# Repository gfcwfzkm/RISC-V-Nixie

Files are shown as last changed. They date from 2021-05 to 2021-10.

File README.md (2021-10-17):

# RISC-V-Nixie
Nixie Clock using the GD32VF103 RISC-V microcontroller by GigaDevices and the swiss precise RTC RV-3032-C7 by Micro Crystal AG.

For tubes, IN-8 tubes will be used as they can be mounted into sockets. Since the original, soviet sockets are quite bulky, individual pin sockets will be mounted instead.

## Status
The current status of the project, which steps are done or still need to be do. Currently only revision A is in testing, a revision that has some slight imperfections that will be tackled in the next revision. Since parts have been already delivered, revision A will be used to extensively test the PCB, in particular the dimming of the tubes and the high-voltage step-up circuitery.
Task | Comments
------------ | -------------
Initial Schematic | :heavy_check_mark:
Initial Layout & BOM | :heavy_check_mark:
Assembling PCB | :heavy_check_mark:
Power-ON Test, Voltage levels | :heavy_check_mark:
Initialising / Testing the MCU | :heavy_check_mark:
Writing basic I/O functions | In Progress... :grey_question:
Writing the clock programm | -

## Images
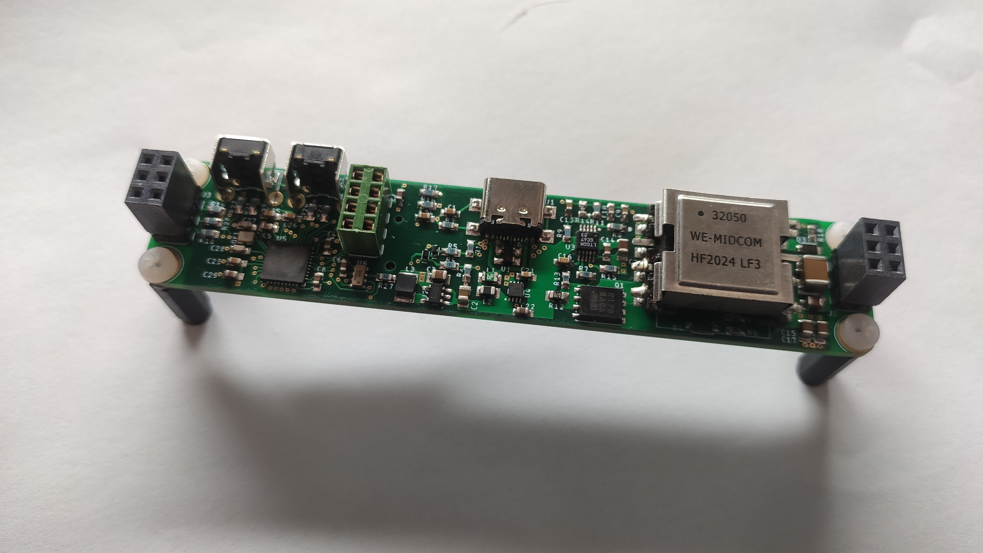
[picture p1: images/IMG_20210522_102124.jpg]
Lower assembled PCB

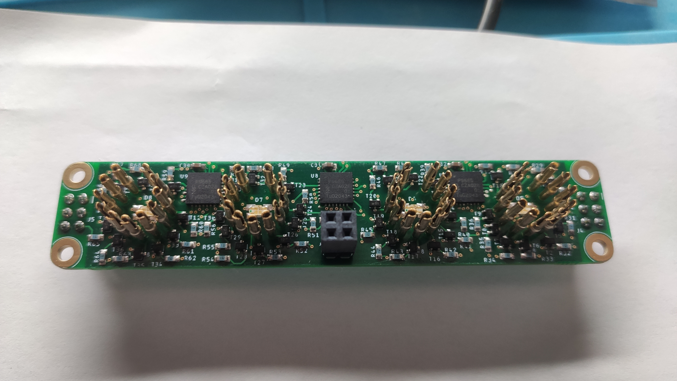
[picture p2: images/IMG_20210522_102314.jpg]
Upper assembled PCB

PCBs + Tubes assembled
Conformal coating TOP
Conformal coating BOTTOM
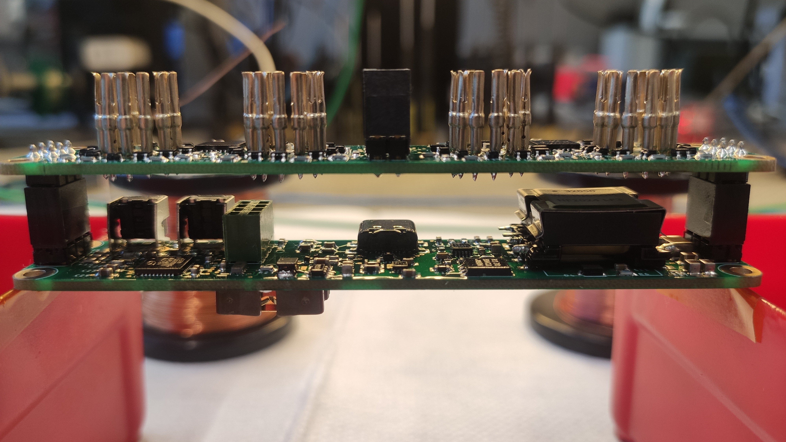
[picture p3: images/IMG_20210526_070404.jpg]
Spacing between high-voltage pins of the upper PCB and the lower PCB's buttons / transformer

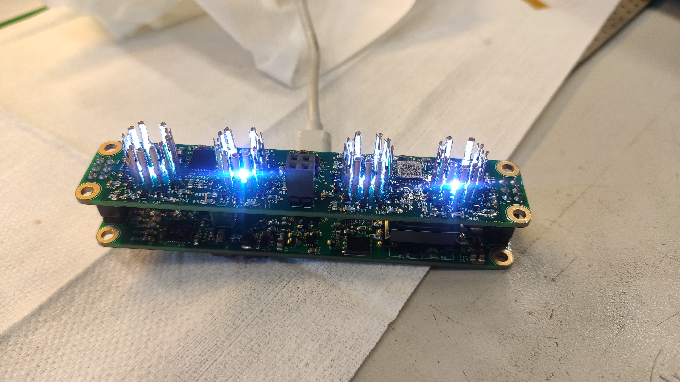
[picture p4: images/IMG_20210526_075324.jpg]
Initial Power test, no magic smoke & all voltages within specs!


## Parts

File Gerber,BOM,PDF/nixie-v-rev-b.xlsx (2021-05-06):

Qty | Value | Device | Package | Parts | Digikey | TME | Ebay | Price single | Price total
1 |  | CONN_02 | 1X02 | J7 | SAM11071-ND |  |  | CHF 1.58 | CHF 1.58
4 |  | WL-SFRW_1206_REC_156120M173000_NOR | WL-SFRW_1206_REC | D5, D6, D7, D8 | 732-13408-1-ND |  |  | CHF 0.87 | CHF 3.48
1 | 1.05M | R-EU_R0603 | R0603 | R10 | RMCF0603FT1M05CT-ND |  |  | CHF 0.09 | CHF 0.09
40 | 1.3k | R-EU_R0603 | R0603 | R29, R30, R31, R32, R33, R34, R35, R36, R37, R38, R39, R40, R41, R42, R43, R44, R45, R46, R47, R48, R49, R50, R51, R52, R53, R54, R55, R56, R57, R58, R59, R60, R61, R62, R63, R64, R65, R66, R67, R68 | 2019-RK73H1JTTD1301FCT-ND |  |  | CHF 0.02 | CHF 0.80
6 | 10 | R-EU_R0603 | R0603 | R7, R13, R70, R75, R78, R81 | 2019-RK73H1JTTD10R0FCT-ND |  |  | CHF 0.09 | CHF 0.54
1 | 10.5k | R-EU_R0603 | R0603 | R11 | 2019-RK73H1JTTD1052FCT-ND |  |  | CHF 0.09 | CHF 0.09
2 | 100 | R-EU_R0603 | R0603 | R4, R5 | 2019-RK73H1JTTD1000FCT-ND |  |  | CHF 0.09 | CHF 0.18
1 | 100k | R-EU_R0603 | R0603 | R24 | 2019-RK73H1JTTD1003FCT-ND |  |  | CHF 0.09 | CHF 0.09
4 | 100nF | C-EUC0603 | C0603 | C1, C24, C25, C26 | 399-C0603C104M5RACAUTOCT-ND |  |  | CHF 0.09 | CHF 0.36
1 | 100pF | C-EUC0603 | C0603 | C10 | 1276-2162-1-ND |  |  | CHF 0.09 | CHF 0.09
7 | 10k | R-EU_R0603 | R0603 | R3, R6, R8, R15, R16, R20, R22 | 2019-RK73H1JTTD1002FCT-ND |  |  | CHF 0.09 | CHF 0.63
1 | 10nF | C-EUC0603 | C0603 | C23 | 445-5662-1-ND |  |  | CHF 0.09 | CHF 0.09
1 | 10uF | C-EUC0805 | C0805 | C3 | 445-173674-1-ND |  |  | CHF 0.44 | CHF 0.44
4 | 115 | R-EU_R0603 | R0603 | R72, R73, R76, R79 | 541-115HCT-ND |  |  | CHF 0.09 | CHF 0.36
1 | 180k | R-EU_R0603 | R0603 | R14 | 2019-RK73H1JTTD1803FCT-ND |  |  | CHF 0.09 | CHF 0.09
4 | 191 | R-EU_R0603 | R0603 | R71, R74, R77, R80 | 2019-RK73H1JTTD1910FCT-ND |  |  | CHF 0.09 | CHF 0.36
11 | 1uF | C-EUC0603 | C0603 | C4, C5, C6, C7, C8, C14, C22, C29, C30, C31, C32 | 445-173628-1-ND |  |  | CHF 0.17 | CHF 1.84
1 | 2.2nF | C-EUC0603 | C0603 | C11 | 1276-6530-1-ND |  |  | CHF 0.09 | CHF 0.09
1 | 20m | R-EU_R0805 | R0805 | R12 | CRF0805-FZ-R020ELFCT-ND |  |  | CHF 0.43 | CHF 0.43
2 | 22 | R-EU_R0603 | R0603 | R25, R26 | 2019-RK73H1JTTD22R0FCT-ND |  |  | CHF 0.09 | CHF 0.18
2 | 22nF | C-EUC0603 | C0603 | C9, C13 | 1276-6534-1-ND |  |  | CHF 0.09 | CHF 0.18
4 | 22uF | C-EUC0805 | C0805 | C15, C17, C18, C20 | 490-12342-1-ND |  |  | CHF 0.52 | CHF 2.08
4 | 3.3k | R-EU_R0603 | R0603 | R18, R19, R27, R28 | 2019-RK73H1JTTD3301FCT-ND |  |  | CHF 0.09 | CHF 0.36
1 | 3.3nF | C-EUC0603 | C0603 | C16 | 478-06035C332K4T2ACT-ND |  |  | CHF 0.09 | CHF 0.09
1 | 30.9k | R-EU_R0603 | R0603 | R9 | 2019-RK73H1JTTD3092FCT-ND |  |  | CHF 0.09 | CHF 0.09
3 | 330 | R-EU_R0603 | R0603 | R17, R21, R23 | 2019-RK73H1JTTD3300FCT-ND |  |  | CHF 0.09 | CHF 0.27
2 | 3V | VESD05A1-02V-G3-08 | SOD-523 | D1, D2 | VESD03C1-02VHG3-08GICT-ND |  |  | CHF 0.35 | CHF 0.70
1 | 3v 1220 Battery | BATTERY1056_KEYSTONE | CH291-1220LF | BT1 | 36-1056-ND |  |  | CHF 1.35 | CHF 1.35
1 | 4.7uF | C-EUC0805 | C0805 | C2 | 587-6301-1-ND |  |  | CHF 0.33 | CHF 0.33
1 | 4.7uH | L1210 | R1210 | L3 | 490-16010-1-ND |  |  | CHF 0.32 | CHF 0.32
1 | 470nF | C-EUC1812 | C1812 | C12 | 445-7993-1-ND |  |  | CHF 1.66 | CHF 1.66
2 | 5.1k | R-EU_R0603 | R0603 | R1, R2 | 2019-RK73H1JTTD5101FCT-ND |  |  | CHF 0.09 | CHF 0.18
1 | 5.4k | R-EU_R0603 | R0603 | R69 | 2019-RN73H1JTTD5421B50CT-ND |  |  | CHF 0.45 | CHF 0.45
1 | 6.8pF | C-EUC0603 | C0603 | C19 | 399-15762-1-ND |  |  | CHF 0.29 | CHF 0.29
1 | 680pF | C-EUC0603 | C0603 | C21 | 399-20505-1-ND |  |  | CHF 0.35 | CHF 0.35
1 | 750032050 | 750032050 | 750032050 | L4 | 732-2128-1-ND |  |  | CHF 4.34 | CHF 4.34
1 | 8MHz | RESONATOR-8MHZSMD_3.2X1.3 | RESONATOR-SMD-3.2X1.3 | Y1 | 490-17958-1-ND |  |  | CHF 0.23 | CHF 0.23
2 | Switch Omron | 31-XX | B3F-31XX | S1, S2 | SW1050-ND |  |  | CHF 0.41 | CHF 0.82
1 | ESH1JMRSG | ESH1JMRSG | MICROSMA | D3 | ESH1JMRSGCT-ND |  |  | CHF 0.41 | CHF 0.41
1 | ESP-01 | CONN_04X2 | 2X4 | J6 | A106657-ND |  |  | CHF 1.21 | CHF 1.21
2 | FromLowerPCB | CONN_03X2FEMALE | 2X3 | J4, J5 | 609-5718-ND |  |  | CHF 0.40 | CHF 0.80
1 | GD32VF103T | GD32VF103T | QFN-36 | U5 |  | GD32VF103TBU6 |  | CHF 2.30 | CHF 2.30
1 | Ih 750mA | PTC_FUSE0805 | R0805 | L1 | 507-1814-1-ND |  |  | CHF 0.16 | CHF 0.16
1 | LT3757A_MSOP | LT3757A_MSOP | MSOP10_POWER | U3 | LT3757AEMSE#PBF-ND |  |  | CHF 4.96 | CHF 4.96
1 | MBR0520LT1G | MBR0520LT1G | SOD-123 | D4 | MBR0580S1-7DICT-ND |  |  | CHF 0.26 | CHF 0.26
1 | MCP1603 | MCP1603 | TSOT23-5 | U2 | MCP1603T-330I/OSCT-ND |  |  | CHF 0.93 | CHF 0.93
4 | MOUNT-PAD-ROUND2.8 |  |  |  | 732-13005-ND |  |  | CHF 0.95 | CHF 3.80
4 | MOUNT-PAD-ROUND2.8 |  |  |  | 732-12861-ND |  |  | CHF 0.55 | CHF 2.20
8 | MOUNT-PAD-ROUND2.8 |  |  |  | 145-50M025045P006-ND |  |  | CHF 0.13 | CHF 1.04
8 | MOUNT-PAD-ROUND2.8 | MOUNT-PAD-ROUND2.8 |  |  | RPC2983-ND |  |  | CHF 0.14 | CHF 1.12
41 | MSD42WT1G | MSD42WT1G | SC70-3-R | T1, T2, T3, T4, T5, T6, T7, T8, T9, T10, T11, T12, T13, T14, T15, T16, T17, T18, T19, T20, T21, T22, T23, T24, T25, T26, T27, T28, T29, T30, T31, T32, T33, T34, T35, T36, T37, T38, T39, T40, T41 | MSD42WT1GOSCT-ND |  |  | CHF 0.15 | CHF 6.12
3 | PCA9685BS | PCA9685BS | HVQFN28 | U7, U8, U9 | 568-5305-1-ND |  |  | CHF 2.28 | CHF 6.84
1 | PRTR5V0U2X | PRTR5V0U2X | SOT143B | U1 | 1727-3884-1-ND |  |  | CHF 0.43 | CHF 0.43
1 | RV-3032-C7 | RV-3032-C7 | RV-3028-C7 | U6 |  |  |  |  | CHF 0.00
1 | Reset | MOMENTARY-SWITCH-SPST-SMD-6.0X3.5MM | TACTILE_SWITCH_SMD_6.0X3.5MM | S3 | CKN10388CT-ND |  |  | CHF 0.50 | CHF 0.50
1 | SIR170DP | SIRA36DP | SO-08_POWERPAK | Q1 | SIR170DP-T1-RE3CT-ND |  |  | CHF 1.82 | CHF 1.82
4 | IN-8 | IN-8SMALL | IN-8 | N1, N2, N3, N4 |  |  | Random Ebay Seller | CHF 10.00 | CHF 40.00
40 | TubeSockets | TubeSockets | Socket | N1, N2, N3, N4 |  |  | RandomEbaySeller | CHF 0.10 | CHF 4.00
1 | TPS22965 | TPS22965 | WSON-8 | U4 | 296-42376-1-ND |  |  | CHF 0.93 | CHF 0.93
2 | ToUpperPCB | CONN_03X2FEMALE | 2X3 | J2, J3 | SAM15144-ND |  |  | CHF 1.97 | CHF 3.94
1 | USB41XX-GF-AMIXED | USB41XX-GF-AMIXED | USB4105-GF-A | J1 | 490-17958-1-ND |  |  | CHF 1.43 | CHF 1.43
1 | f-bead | L-COIL | R0805 | L2 | 445-172904-1-ND |  |  | CHF 0.11 | CHF 0.11
 |  |  |  |  |  |  |  | PRICE TOTAL | CHF 111.20

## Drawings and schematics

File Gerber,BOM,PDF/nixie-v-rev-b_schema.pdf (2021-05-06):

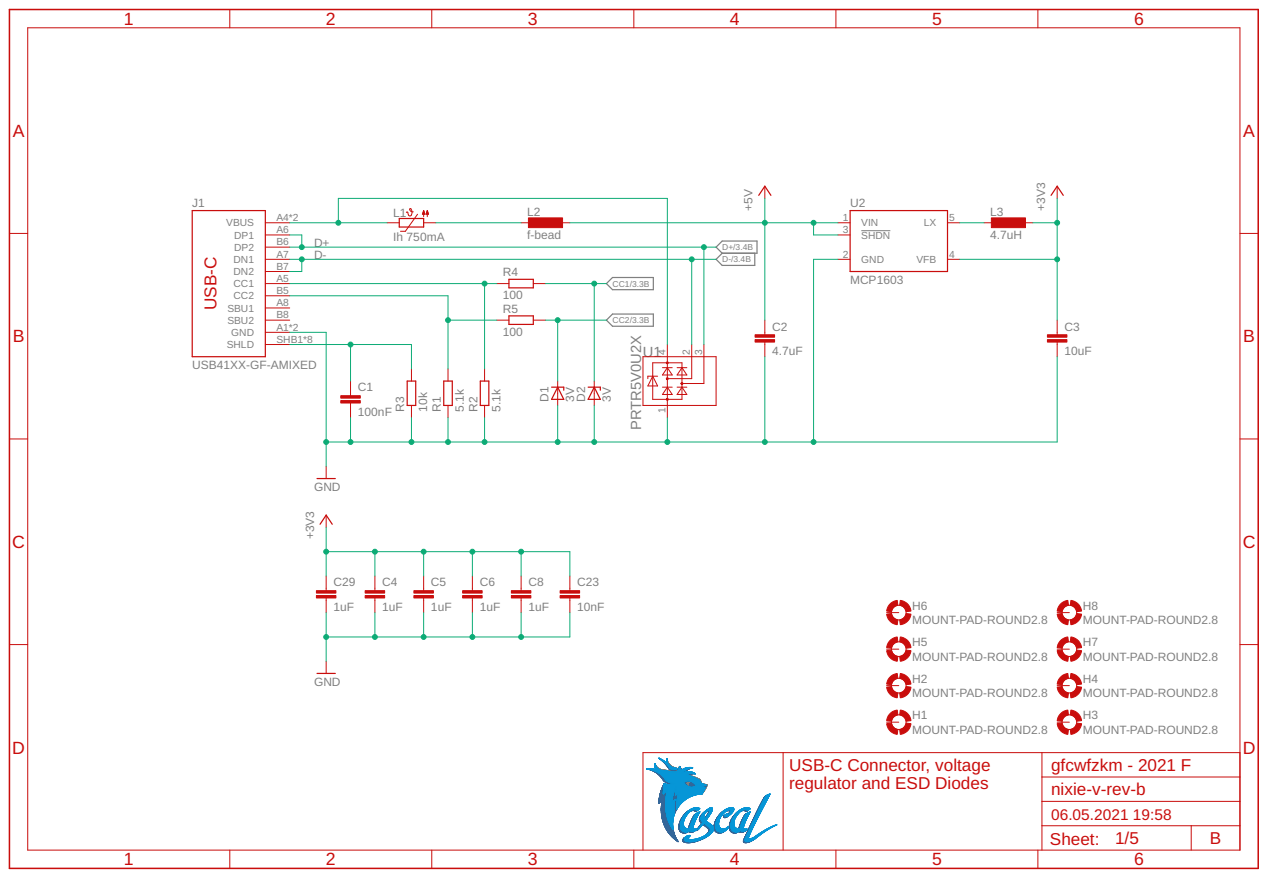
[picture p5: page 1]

regulator and ESD Diodes

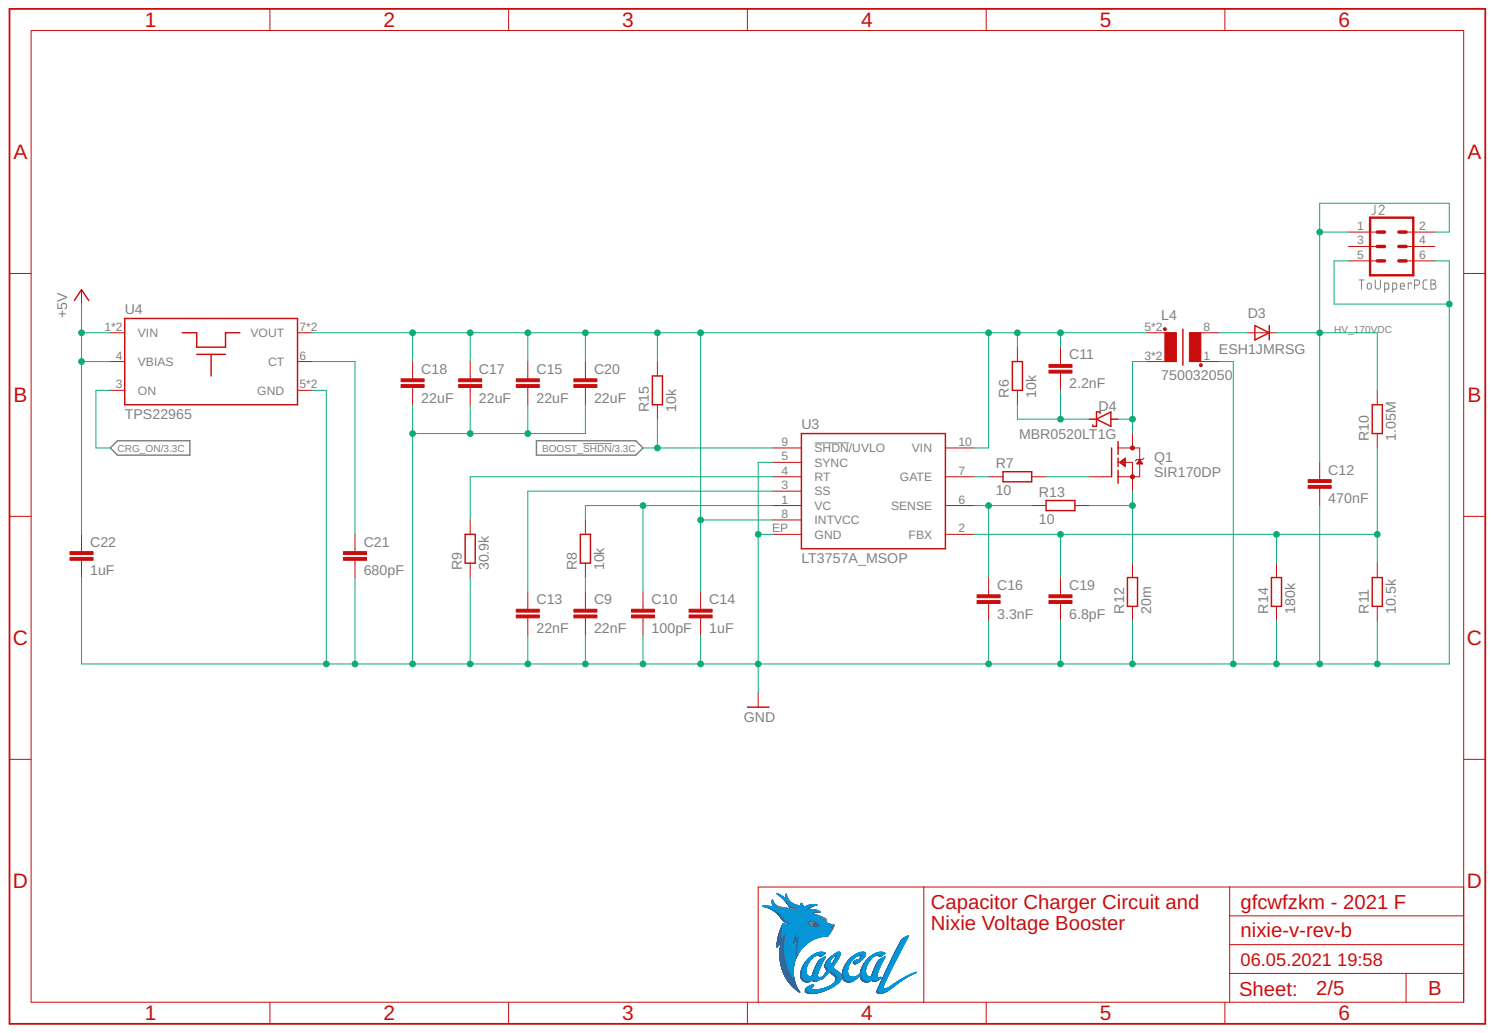
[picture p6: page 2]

Capacitor Charger Circuit and
Nixie Voltage Booster

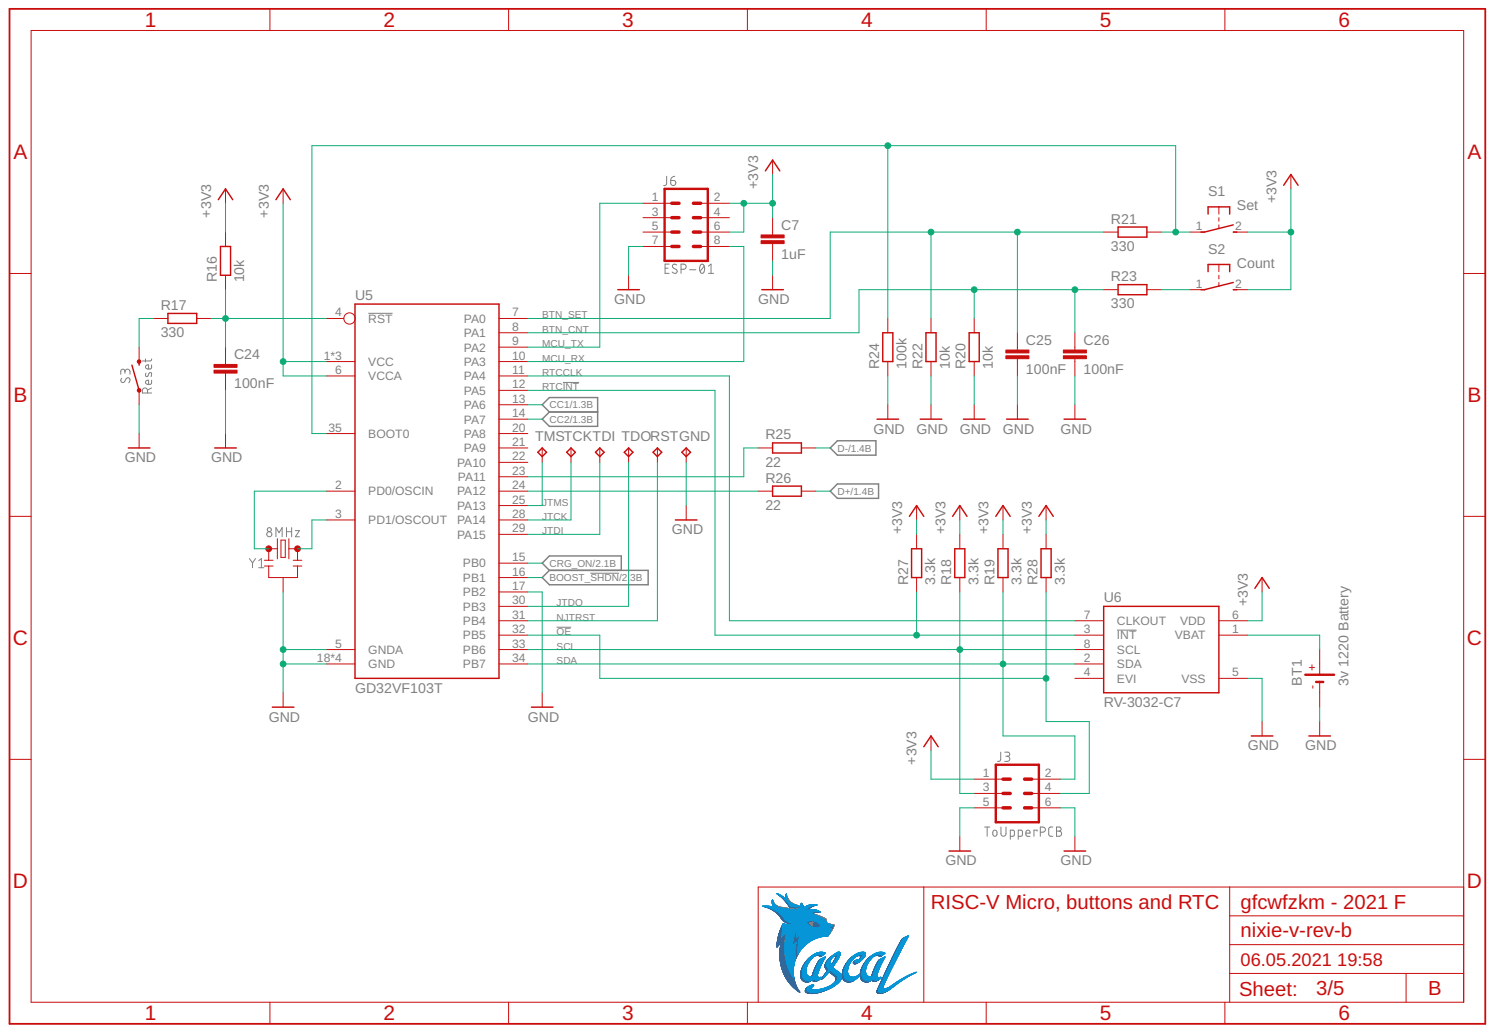
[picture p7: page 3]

8 PA0 BTN_CNT BTN_SET
9 PA1 MCU_TX MCU_RX

24 PA11
25 PA12 | JTCK

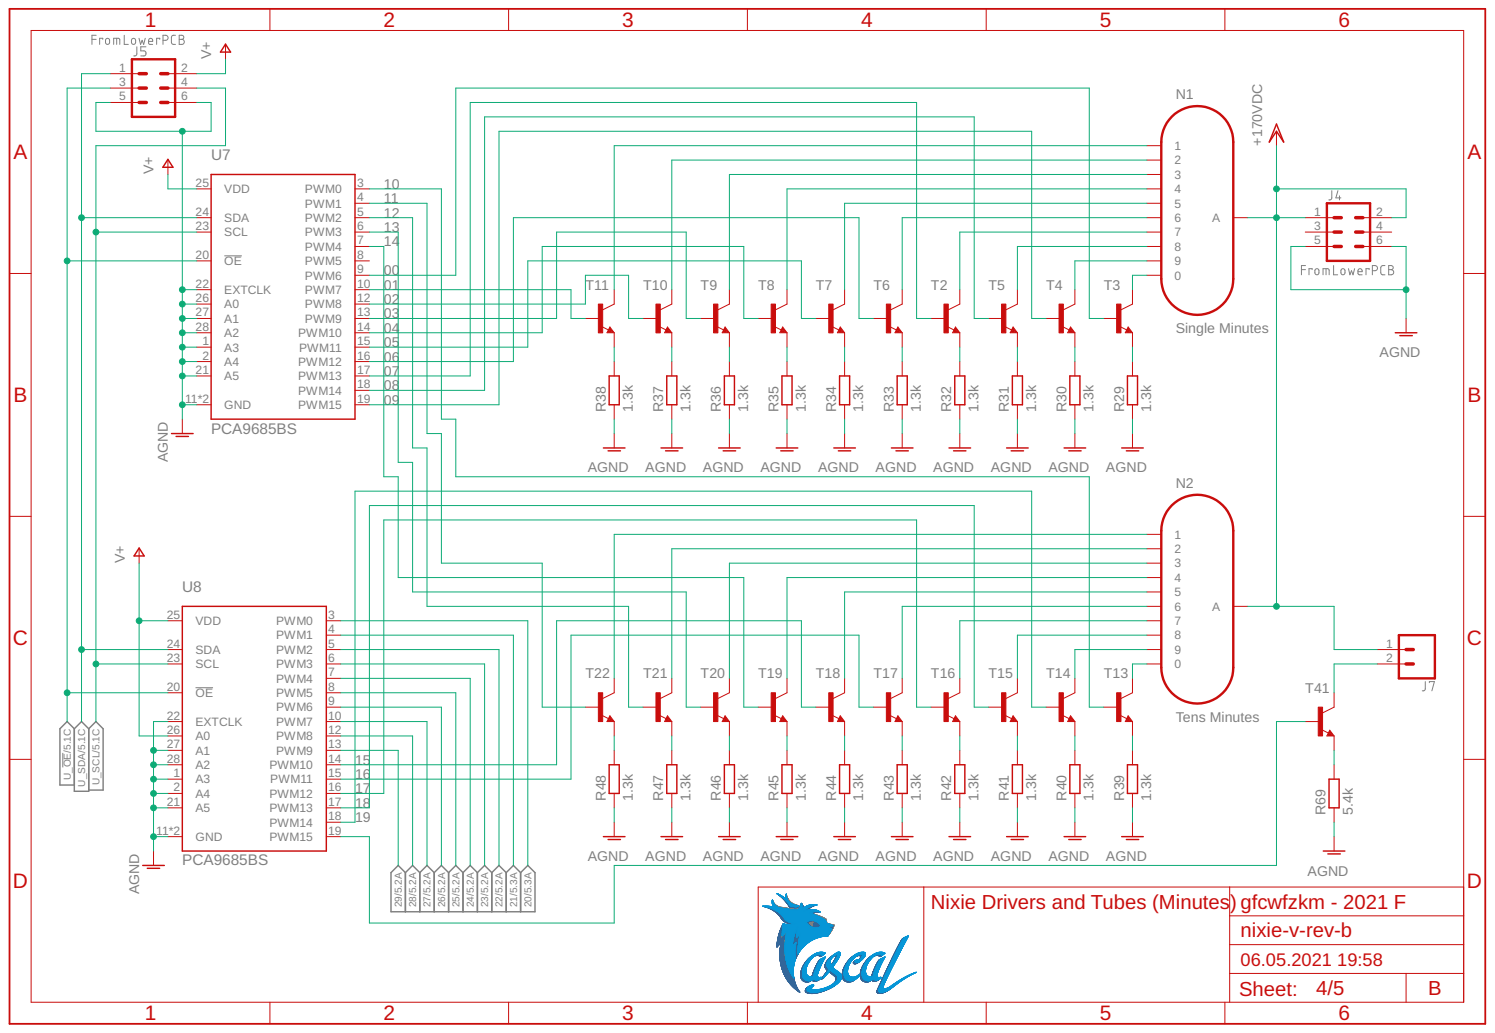
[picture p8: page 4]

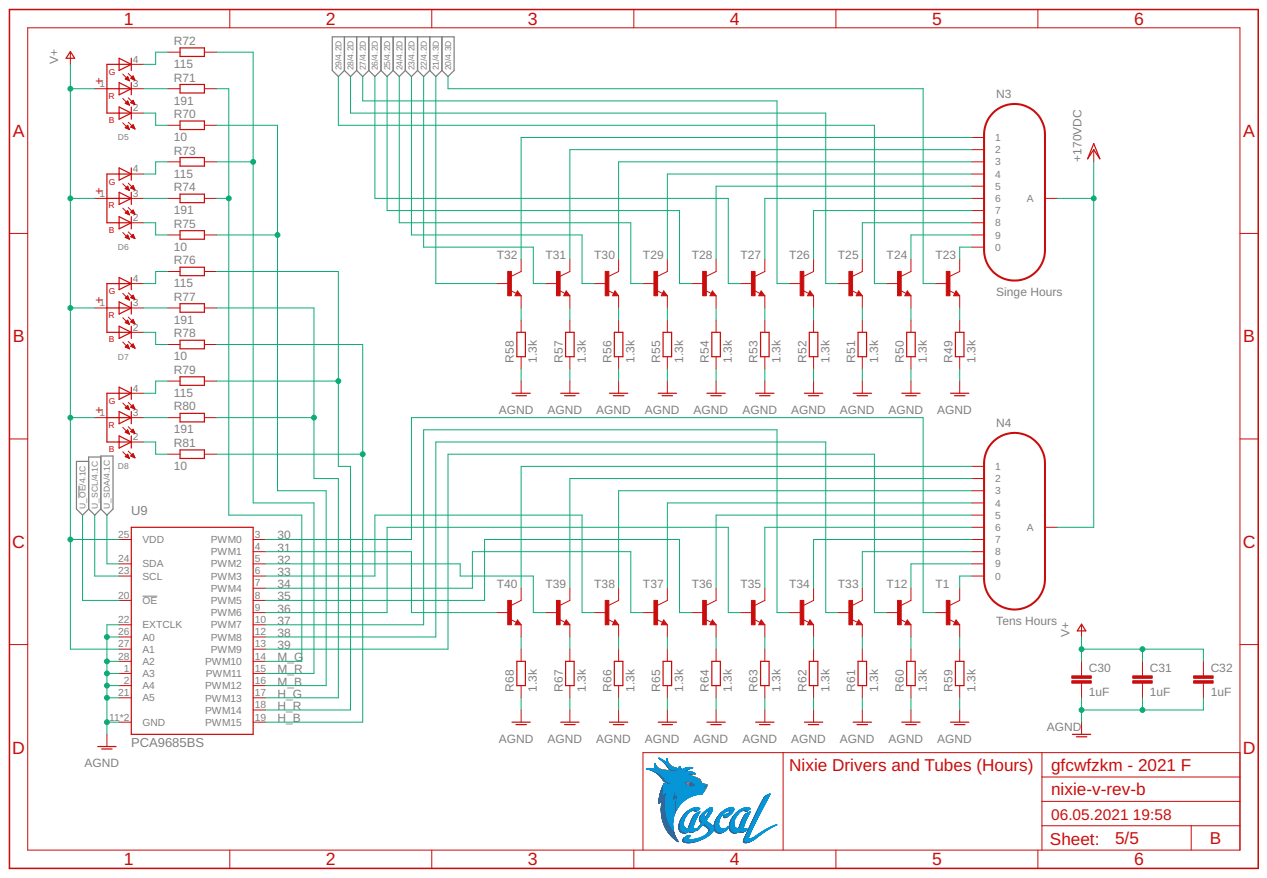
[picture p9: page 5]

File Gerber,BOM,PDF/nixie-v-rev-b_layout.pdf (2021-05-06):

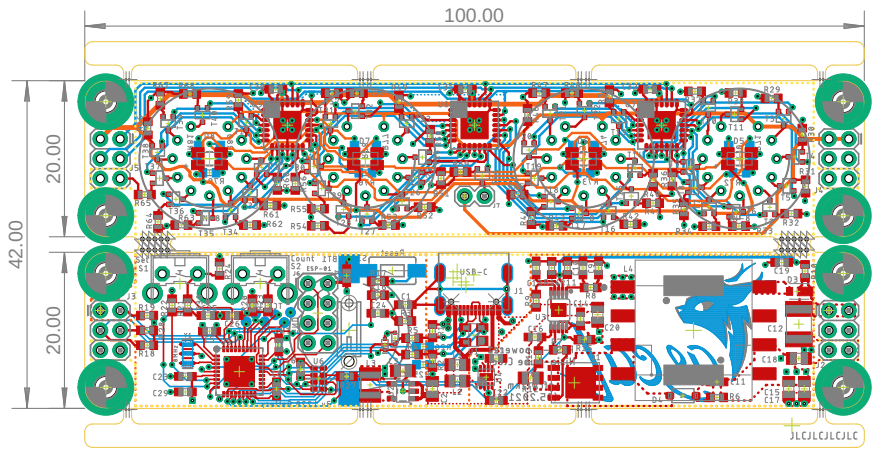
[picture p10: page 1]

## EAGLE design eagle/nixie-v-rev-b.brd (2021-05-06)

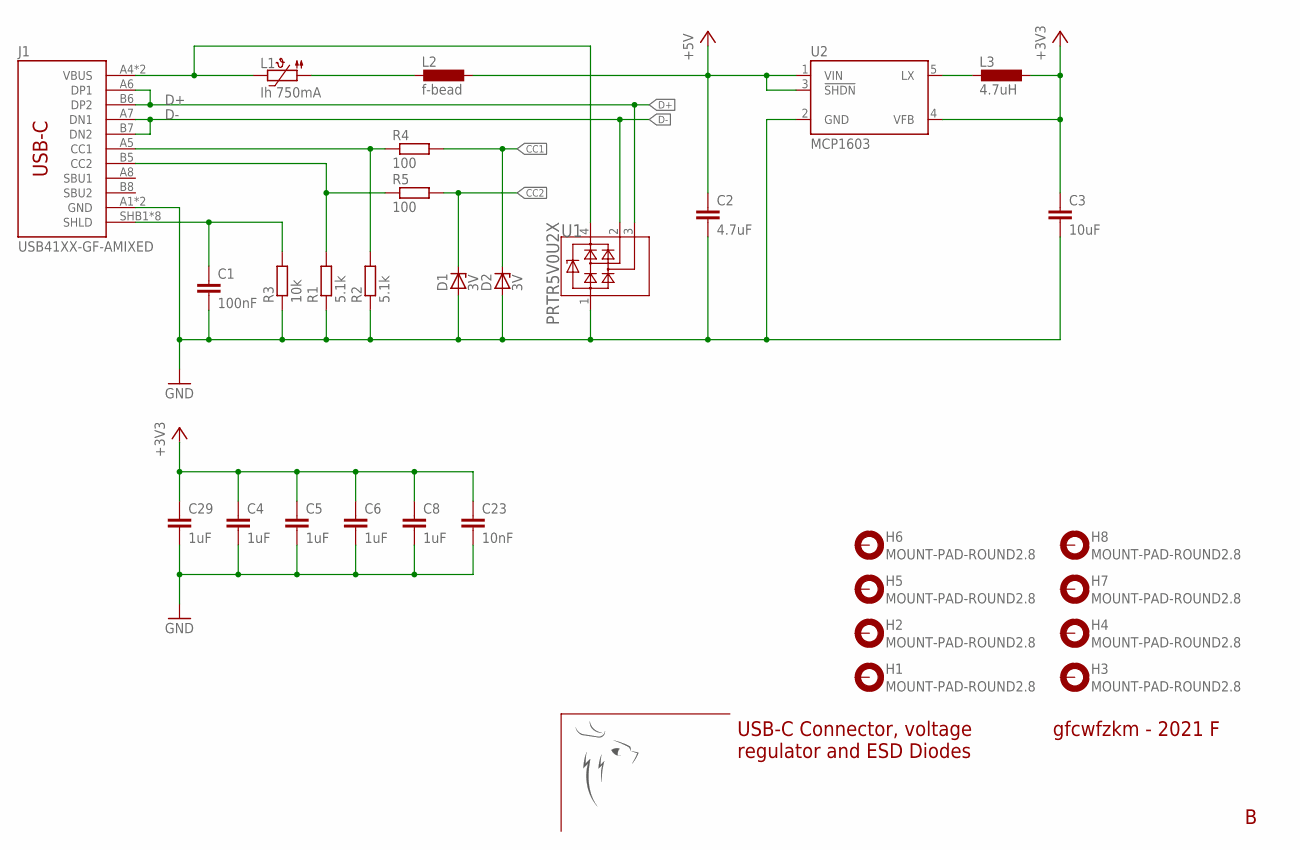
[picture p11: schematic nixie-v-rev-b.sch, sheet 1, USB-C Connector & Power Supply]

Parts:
C1: 100nF; C0603
C2: 4.7uF; C0805
C3: 10uF; C0805
C4, C5, C6, C8, C29: 1uF; C0603
C23: 10nF; C0603
D1, D2: 3V; SOD-523
H1, H2, H3, H4, H5, H6, H7, H8: MOUNT-PAD-ROUND2.8; 2,8-PAD
J1: USB41XX-GF-AMIXED; USB4105-GF-A
L1: Ih 750mA; R0805
L2: f-bead; R0805
L3: 4.7uH; R1210
R1, R2: 5.1k; R0603
R3: 10k; R0603
R4, R5: 100; R0603
U1: PRTR5V0U2X; SOT143B
U2: MCP1603; TSOT23-5
U$1: LOGO_PASCAL_GESELL30MM; LOGO_30MM

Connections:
+3V3: C3.1, C4.1, C5.1, C6.1, C8.1, C23.1, C29.1, L3.1, U2.4 (VFB); also elsewhere on the board
+5V: C2.1, L2.1, U2.1 (VIN), U2.3 (!SHDN); also elsewhere on the board
CC1: D2.C, R4.2; also elsewhere on the board
CC2: D1.C, R5.2; also elsewhere on the board
D+: J1.A6 (DP1), J1.B6 (DP2), U1.3; also elsewhere on the board
D-: J1.A7 (DN1), J1.B7 (DN2), U1.2; also elsewhere on the board
GND: C1.2, C2.2, C3.2, C4.2, C5.2, C6.2, C8.2, C23.2, C29.2, D1.A, D2.A, J1.A1 (GND), J1.B1 (GND), R1.1, R2.1, R3.1, U1.1, U2.2 (GND); also elsewhere on the board
LX: L3.2, U2.5 (LX)
unnamed: C1.1, J1.SHB1 (SHLD), J1.SHB2 (SHLD), J1.SHB3 (SHLD), J1.SHB4 (SHLD), J1.SHT1 (SHLD), J1.SHT2 (SHLD), J1.SHT3 (SHLD), J1.SHT4 (SHLD), R3.2
unnamed: J1.B5 (CC2), R1.2, R5.1
unnamed: J1.A5 (CC1), R2.2, R4.1
unnamed: L1.1, L2.2
VBUS: J1.A4 (VBUS), J1.B4 (VBUS), L1.2, U1.4

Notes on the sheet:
gfcwfzkm - 2021 F
USB-C Connector, voltage regulator and ESD Diodes

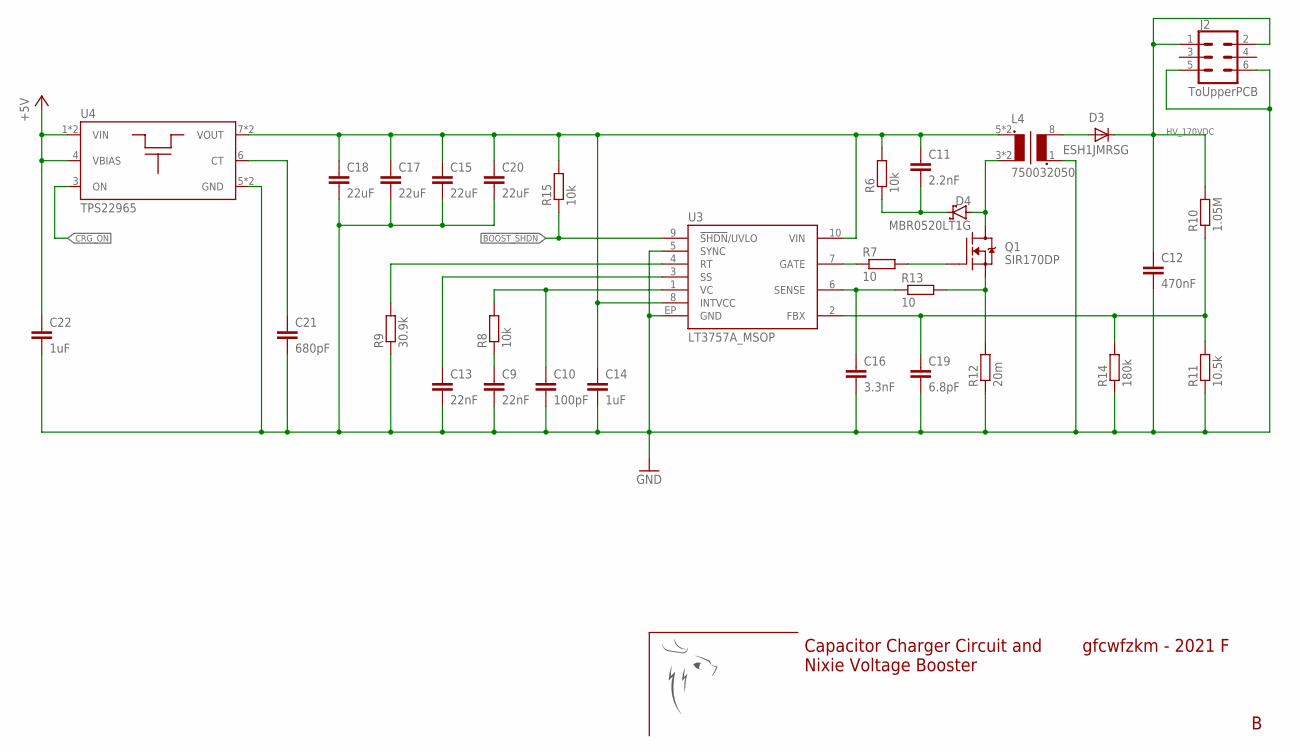
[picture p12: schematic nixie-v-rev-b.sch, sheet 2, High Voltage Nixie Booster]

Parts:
C9, C13: 22nF; C0603
C10: 100pF; C0603
C11: 2.2nF; C0603
C12: 470nF; C1812
C14, C22: 1uF; C0603
C15, C17, C18, C20: 22uF; C0805
C16: 3.3nF; C0603
C19: 6.8pF; C0603
C21: 680pF; C0603
D3: ESH1JMRSG; MICROSMA
D4: MBR0520LT1G; SOD-123
J2: ToUpperPCB; 2X3
L4: 750032050
Q1: SIR170DP; SO-08_POWERPAK
R6, R8, R15: 10k; R0603
R7, R13: 10; R0603
R9: 30.9k; R0603
R10: 1.05M; R0603
R11: 10.5k; R0603
R12: 20m; R0805
R14: 180k; R0603
U3: LT3757A_MSOP; MSOP10_POWER
U4: TPS22965; WSON-8
U$2: LOGO_PASCAL_GESELLEMPTY; EMPTY

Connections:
+5V: C22.1, U4.1 (VIN), U4.2 (VIN), U4.4 (VBIAS); also elsewhere on the board
BOOST_!SHDN: R15.1, U3.9 (!SHDN!/UVLO); also elsewhere on the board
CRG_ON: U4.3 (ON); also elsewhere on the board
FBX: C19.1, R10.1, R11.2, R14.2, U3.2 (FBX)
GATE: R7.1, U3.7 (GATE)
GND: C9.2, C10.2, C12.2, C13.2, C14.2, C15.2, C16.2, C17.2, C18.2, C19.2, C20.2, C21.2, C22.2, J2.5, J2.6, L4.1 (S1), R9.1, R11.1, R12.1, R14.1, U3.5 (SYNC), U3.EP (GND), U4.5 (GND), U4.TP (GND); also elsewhere on the board
HV_170VDC: C12.1, D3.C, J2.1, J2.2, R10.2
unnamed: C11.2, D4.C, R6.1
unnamed: Q1.4 (G), R7.2
unnamed: D3.A, L4.8 (S2)
unnamed: C9.1, R8.1
unnamed: Q1.1 (S), Q1.2 (S), Q1.3 (S), R12.2, R13.2
unnamed: D4.A, L4.3 (P2), L4.4 (P2), Q1.5 (D), Q1.6 (D), Q1.7 (D), Q1.8 (D), Q1.THERMAL (D)
unnamed: C21.1, U4.6 (CT)
RT: R9.2, U3.4 (RT)
SENSE: C16.1, R13.1, U3.6 (SENSE)
SS: C13.1, U3.3 (SS)
SUP_BOOST: C11.1, C14.1, C15.1, C17.1, C18.1, C20.1, L4.5 (P1), L4.6 (P1), R6.2, R15.2, U3.8 (INTVCC), U3.10 (VIN), U4.7 (VOUT), U4.8 (VOUT)
VC: C10.1, R8.2, U3.1 (VC)

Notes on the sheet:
Capacitor Charger Circuit and Nixie Voltage Booster
gfcwfzkm - 2021 F

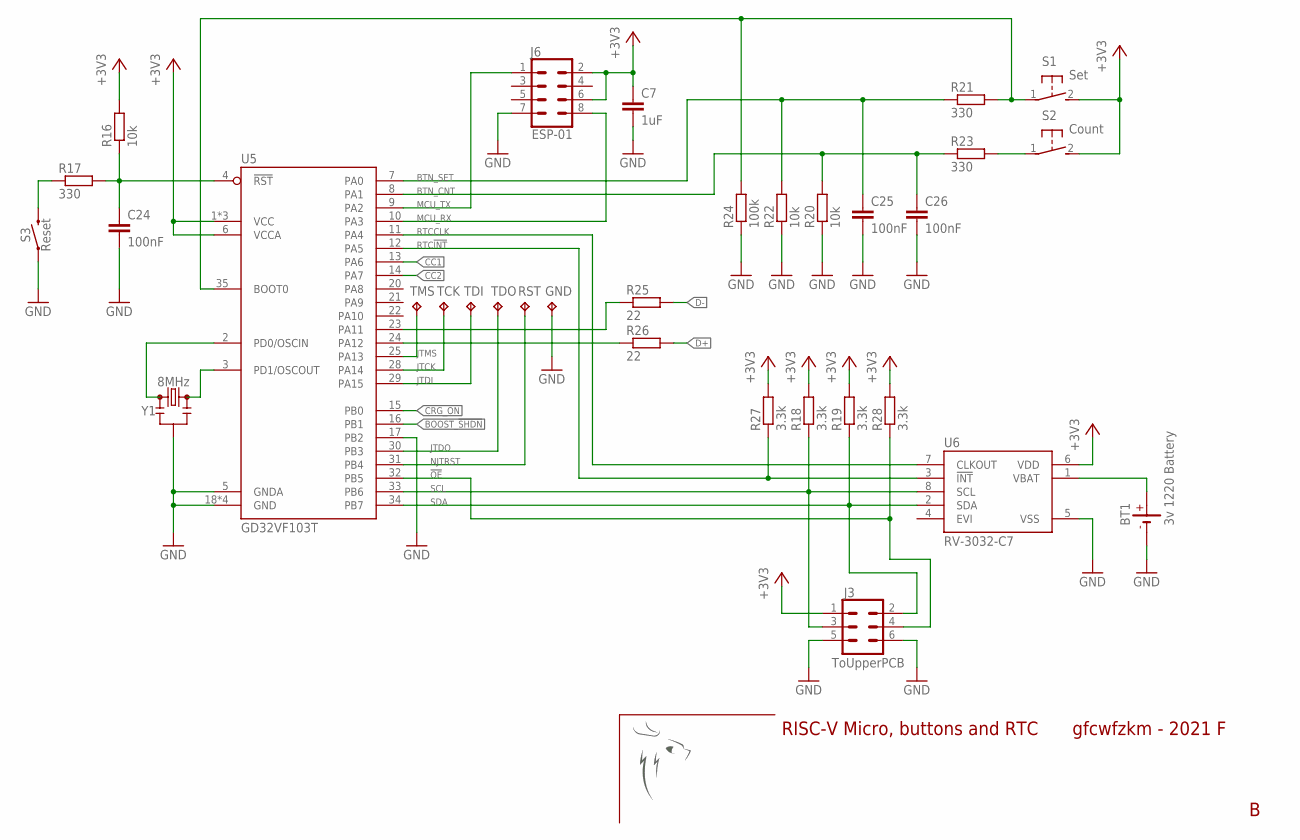
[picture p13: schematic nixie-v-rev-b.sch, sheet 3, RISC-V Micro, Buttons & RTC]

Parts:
BT1: 3v 1220 Battery; CH291-1220LF
C7: 1uF; C0603
C24, C25, C26: 100nF; C0603
GND: TPB1,27; B1,27
J3: ToUpperPCB; 2X3
J6: ESP-01; 2X4
R16, R20, R22: 10k; R0603
R17, R21, R23: 330; R0603
R18, R19, R27, R28: 3.3k; R0603
R24: 100k; R0603
R25, R26: 22; R0603
RST: TPB1,27; B1,27
S1: Set; B3F-31XX
S2: Count; B3F-31XX
S3: Reset; TACTILE_SWITCH_SMD_6.0X3.5MM
TCK: TPB1,27; B1,27
TDI: TPB1,27; B1,27
TDO: TPB1,27; B1,27
TMS: TPB1,27; B1,27
U5: GD32VF103T; QFN-36
U6: RV-3032-C7; RV-3028-C7
U$3: LOGO_PASCAL_GESELLEMPTY; EMPTY
Y1: 8MHz; RESONATOR-SMD-3.2X1.3

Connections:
!OE: J3.4, R28.1, U5.32 (PB5)
+3V3: C7.1, J3.1, J6.2, J6.6, R16.2, R18.2, R19.2, R27.2, R28.2, S1.2 (S), S2.2 (S), U5.1 (VCC), U5.6 (VCCA), U5.19 (VCC), U5.27 (VCC), U6.6 (VDD); also elsewhere on the board
BOOST_!SHDN: U5.16 (PB1); also elsewhere on the board
BTN_CNT: C26.1, R20.2, R23.1, U5.8 (PA1)
BTN_SET: C25.1, R21.1, R22.2, U5.7 (PA0)
CC1: U5.13 (PA6); also elsewhere on the board
CC2: U5.14 (PA7); also elsewhere on the board
CRG_ON: U5.15 (PB0); also elsewhere on the board
D+: R26.2; also elsewhere on the board
D-: R25.2; also elsewhere on the board
GND: BT1.-, C7.2, C24.2, C25.2, C26.2, GND.TP, J3.5, J3.6, J6.7, R20.1, R22.1, R24.1, S3.1, U5.5 (GNDA), U5.17 (PB2), U5.18 (GND), U5.26 (GND), U5.36 (GND), U5.EP (GND), U6.5 (VSS), Y1.2; also elsewhere on the board
JTCK: TCK.TP, U5.28 (PA14)
JTDI: TDI.TP, U5.29 (PA15)
JTDO: TDO.TP, U5.30 (PB3)
JTMS: TMS.TP, U5.25 (PA13)
MCU_RX: J6.8, U5.10 (PA3)
MCU_TX: J6.1, U5.9 (PA2)
unnamed: C24.1, R16.1, R17.2, U5.4 (!RST)
unnamed: R26.1, U5.24 (PA12)
unnamed: R23.2, S2.1
unnamed: U5.3 (PD1/OSCOUT), Y1.3
unnamed: R21.2, R24.2, S1.1, U5.35 (BOOT0)
unnamed: R17.1, S3.2
unnamed: U5.2 (PD0/OSCIN), Y1.1
unnamed: R25.1, U5.23 (PA11)
unnamed: BT1.+, U6.1 (VBAT)
NJTRST: RST.TP, U5.31 (PB4)
RTC!INT: R27.1, U5.12 (PA5), U6.3 (!INT)
RTCCLK: U5.11 (PA4), U6.7 (CLKOUT)
SCL: J3.3, R18.1, U5.33 (PB6), U6.8 (SCL)
SDA: J3.2, R19.1, U5.34 (PB7), U6.2 (SDA)

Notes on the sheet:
RISC-V Micro, buttons and RTC
gfcwfzkm - 2021 F

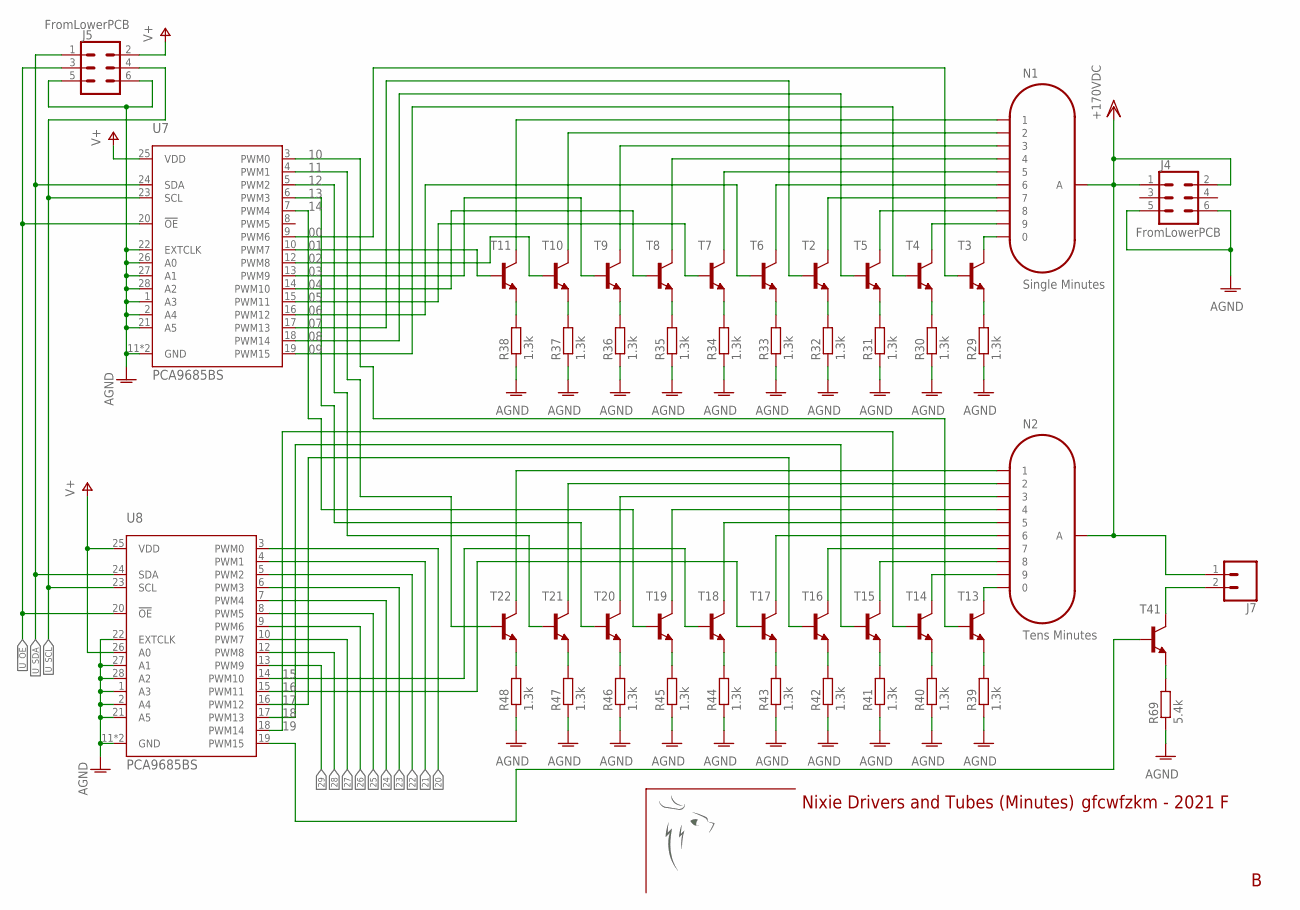
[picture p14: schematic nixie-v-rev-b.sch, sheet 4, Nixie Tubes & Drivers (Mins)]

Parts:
J4, J5: FromLowerPCB; 2X3
J7: CONN_02; 1X02
N1: Single Minutes; IN-8
N2: Tens Minutes; IN-8
R29, R30, R31, R32, R33, R34, R35, R36, R37, R38, R39, R40, R41, R42, R43, R44, R45, R46, R47, R48: 1.3k; R0603
R69: 5.4k; R0603
T2, T3, T4, T5, T6, T7, T8, T9, T10, T11, T13, T14, T15, T16, T17, T18, T19, T20, T21, T22, T41: MSD42WT1G; SC70-3-R
U7, U8: PCA9685BS; HVQFN28
U$4: LOGO_PASCAL_GESELLEMPTY; EMPTY

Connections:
00: T3.1 (B), U7.9 (PWM6)
01: T11.1 (B), U7.10 (PWM7)
02: T10.1 (B), U7.12 (PWM8)
03: T9.1 (B), U7.13 (PWM9)
04: T8.1 (B), U7.14 (PWM10)
05: T7.1 (B), U7.15 (PWM11)
06: T6.1 (B), U7.16 (PWM12)
07: T2.1 (B), U7.17 (PWM13)
08: T5.1 (B), U7.18 (PWM14)
09: T4.1 (B), U7.19 (PWM15)
10: T13.1 (B), U7.3 (PWM0)
11: T22.1 (B), U7.4 (PWM1)
12: T21.1 (B), U7.5 (PWM2)
13: T20.1 (B), U7.6 (PWM3)
14: T19.1 (B), U7.7 (PWM4)
15: T18.1 (B), U8.14 (PWM10)
16: T17.1 (B), U8.15 (PWM11)
17: T16.1 (B), U8.16 (PWM12)
18: T15.1 (B), U8.17 (PWM13)
19: T14.1 (B), U8.18 (PWM14)
20: U8.3 (PWM0); also elsewhere on the board
21: U8.4 (PWM1); also elsewhere on the board
22: U8.5 (PWM2); also elsewhere on the board
23: U8.6 (PWM3); also elsewhere on the board
24: U8.7 (PWM4); also elsewhere on the board
25: U8.8 (PWM5); also elsewhere on the board
26: U8.9 (PWM6); also elsewhere on the board
27: U8.10 (PWM7); also elsewhere on the board
28: U8.12 (PWM8); also elsewhere on the board
29: U8.13 (PWM9); also elsewhere on the board
+170VDC: J4.1, J4.2, J7.1, N1.A, N2.A; also elsewhere on the board
AGND: J4.5, J4.6, J5.5, J5.6, R29.1, R30.1, R31.1, R32.1, R33.1, R34.1, R35.1, R36.1, R37.1, R38.1, R39.1, R40.1, R41.1, R42.1, R43.1, R44.1, R45.1, R46.1, R47.1, R48.1, R69.1, U7.1 (A3), U7.2 (A4), U7.11 (GND), U7.21 (A5), U7.22 (EXTCLK), U7.26 (A0), U7.27 (A1), U7.28 (A2), U7.TH (GND), U8.1 (A3), U8.2 (A4), U8.11 (GND), U8.21 (A5), U8.22 (EXTCLK), U8.27 (A1), U8.28 (A2), U8.TH (GND); also elsewhere on the board
unnamed: N1.0, T3.3 (C)
unnamed: J7.2, T41.3 (C)
unnamed: R69.2, T41.2 (E)
unnamed: T41.1 (B), U8.19 (PWM15)
unnamed: N1.9, T4.3 (C)
unnamed: N1.8, T5.3 (C)
unnamed: N1.7, T2.3 (C)
unnamed: N1.6, T6.3 (C)
unnamed: N1.5, T7.3 (C)
unnamed: N1.4, T8.3 (C)
unnamed: N1.3, T9.3 (C)
unnamed: N1.2, T10.3 (C)
unnamed: N1.1, T11.3 (C)
unnamed: R29.2, T3.2 (E)
unnamed: R38.2, T11.2 (E)
unnamed: R37.2, T10.2 (E)
unnamed: R36.2, T9.2 (E)
unnamed: R35.2, T8.2 (E)
unnamed: R34.2, T7.2 (E)
unnamed: R33.2, T6.2 (E)
unnamed: R32.2, T2.2 (E)
unnamed: R31.2, T5.2 (E)
unnamed: R30.2, T4.2 (E)
unnamed: N2.0, T13.3 (C)
unnamed: N2.9, T14.3 (C)
unnamed: N2.8, T15.3 (C)
unnamed: N2.7, T16.3 (C)
unnamed: N2.6, T17.3 (C)
unnamed: N2.5, T18.3 (C)
unnamed: N2.4, T19.3 (C)
unnamed: N2.3, T20.3 (C)
unnamed: N2.2, T21.3 (C)
unnamed: N2.1, T22.3 (C)
unnamed: R39.2, T13.2 (E)
unnamed: R48.2, T22.2 (E)
unnamed: R47.2, T21.2 (E)
unnamed: R46.2, T20.2 (E)
unnamed: R45.2, T19.2 (E)
unnamed: R44.2, T18.2 (E)
unnamed: R43.2, T17.2 (E)
unnamed: R42.2, T16.2 (E)
unnamed: R41.2, T15.2 (E)
unnamed: R40.2, T14.2 (E)
U_!OE: J5.3, U7.20 (!OE), U8.20 (!OE); also elsewhere on the board
U_SCL: J5.4, U7.23 (SCL), U8.23 (SCL); also elsewhere on the board
U_SDA: J5.1, U7.24 (SDA), U8.24 (SDA); also elsewhere on the board
V+: J5.2, U7.25 (VDD), U8.25 (VDD), U8.26 (A0); also elsewhere on the board

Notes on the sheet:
Nixie Drivers and Tubes (Minutes)
gfcwfzkm - 2021 F

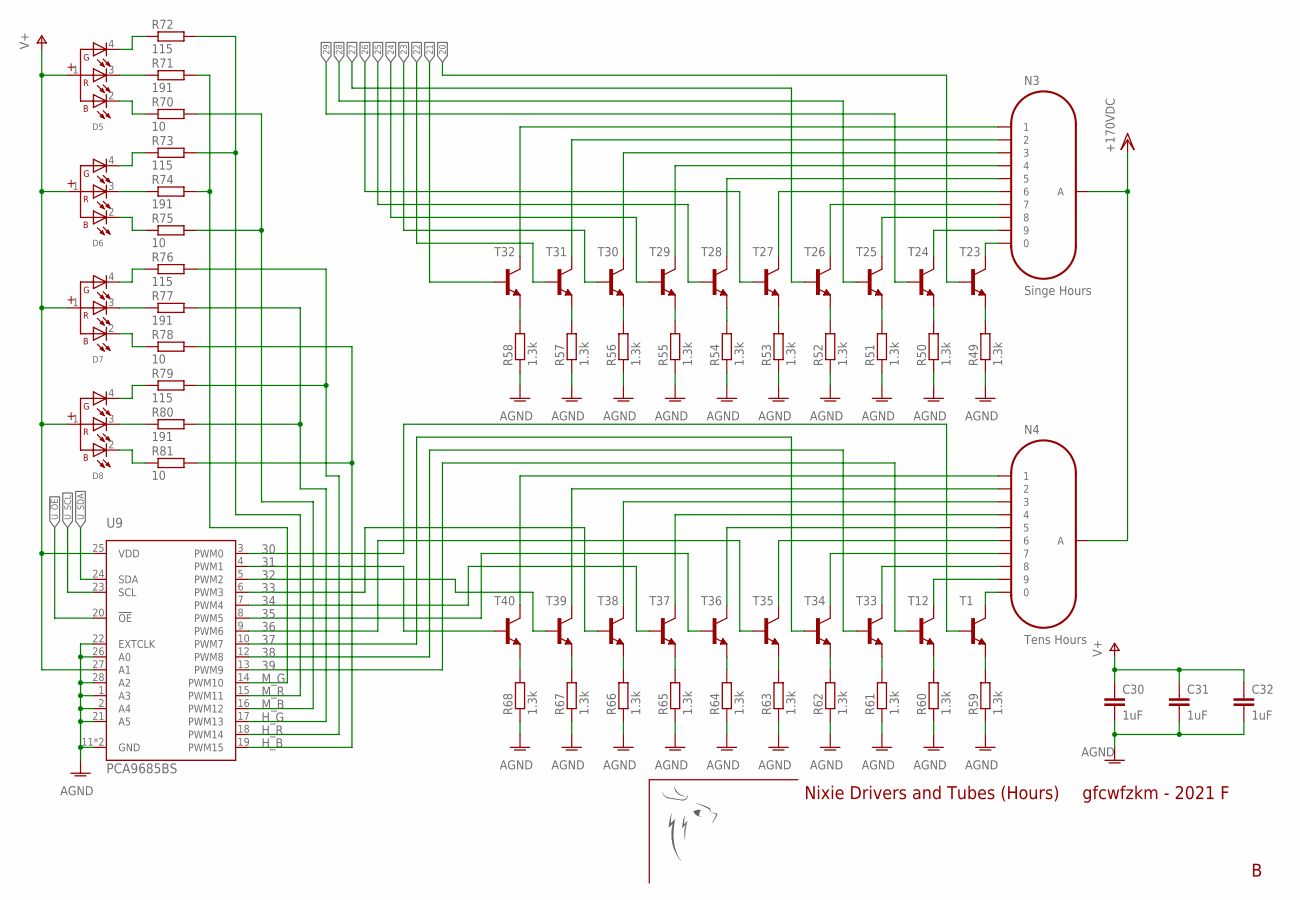
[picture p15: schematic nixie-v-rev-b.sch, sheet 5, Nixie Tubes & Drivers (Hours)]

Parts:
C30, C31, C32: 1uF; C0603
D5, D6, D7, D8: WL-SFRW_1206_REC_156120M173000_NOR; WL-SFRW_1206_REC
N3: Singe Hours; IN-8
N4: Tens Hours; IN-8
R49, R50, R51, R52, R53, R54, R55, R56, R57, R58, R59, R60, R61, R62, R63, R64, R65, R66, R67, R68: 1.3k; R0603
R70, R75, R78, R81: 10; R0603
R71, R74, R77, R80: 191; R0603
R72, R73, R76, R79: 115; R0603
T1, T12, T23, T24, T25, T26, T27, T28, T29, T30, T31, T32, T33, T34, T35, T36, T37, T38, T39, T40: MSD42WT1G; SC70-3-R
U9: PCA9685BS; HVQFN28
U$5: LOGO_PASCAL_GESELLEMPTY; EMPTY

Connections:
20: T23.1 (B); also elsewhere on the board
21: T32.1 (B); also elsewhere on the board
22: T31.1 (B); also elsewhere on the board
23: T30.1 (B); also elsewhere on the board
24: T29.1 (B); also elsewhere on the board
25: T28.1 (B); also elsewhere on the board
26: T27.1 (B); also elsewhere on the board
27: T26.1 (B); also elsewhere on the board
28: T25.1 (B); also elsewhere on the board
29: T24.1 (B); also elsewhere on the board
30: T1.1 (B), U9.3 (PWM0)
31: T40.1 (B), U9.4 (PWM1)
32: T39.1 (B), U9.5 (PWM2)
33: T38.1 (B), U9.6 (PWM3)
34: T37.1 (B), U9.7 (PWM4)
35: T36.1 (B), U9.8 (PWM5)
36: T35.1 (B), U9.9 (PWM6)
37: T34.1 (B), U9.10 (PWM7)
38: T33.1 (B), U9.12 (PWM8)
39: T12.1 (B), U9.13 (PWM9)
+170VDC: N3.A, N4.A; also elsewhere on the board
AGND: C30.2, C31.2, C32.2, R49.1, R50.1, R51.1, R52.1, R53.1, R54.1, R55.1, R56.1, R57.1, R58.1, R59.1, R60.1, R61.1, R62.1, R63.1, R64.1, R65.1, R66.1, R67.1, R68.1, U9.1 (A3), U9.2 (A4), U9.11 (GND), U9.21 (A5), U9.22 (EXTCLK), U9.26 (A0), U9.28 (A2), U9.TH (GND); also elsewhere on the board
H_B: R78.2, R81.2, U9.19 (PWM15)
H_G: R77.2, R80.2, U9.17 (PWM13)
H_R: R76.2, R79.2, U9.18 (PWM14)
M_B: R70.2, R75.2, U9.16 (PWM12)
M_G: R71.2, R74.2, U9.14 (PWM10)
M_R: R72.2, R73.2, U9.15 (PWM11)
unnamed: N3.0, T23.3 (C)
unnamed: N3.9, T24.3 (C)
unnamed: N3.8, T25.3 (C)
unnamed: N3.7, T26.3 (C)
unnamed: N3.6, T27.3 (C)
unnamed: N3.5, T28.3 (C)
unnamed: N3.4, T29.3 (C)
unnamed: N3.3, T30.3 (C)
unnamed: N3.2, T31.3 (C)
unnamed: N3.1, T32.3 (C)
unnamed: R49.2, T23.2 (E)
unnamed: R58.2, T32.2 (E)
unnamed: R57.2, T31.2 (E)
unnamed: R56.2, T30.2 (E)
unnamed: R55.2, T29.2 (E)
unnamed: R54.2, T28.2 (E)
unnamed: R53.2, T27.2 (E)
unnamed: R52.2, T26.2 (E)
unnamed: R51.2, T25.2 (E)
unnamed: R50.2, T24.2 (E)
unnamed: N4.0, T1.3 (C)
unnamed: N4.9, T12.3 (C)
unnamed: N4.8, T33.3 (C)
unnamed: N4.7, T34.3 (C)
unnamed: N4.6, T35.3 (C)
unnamed: N4.5, T36.3 (C)
unnamed: N4.4, T37.3 (C)
unnamed: N4.3, T38.3 (C)
unnamed: N4.2, T39.3 (C)
unnamed: N4.1, T40.3 (C)
unnamed: R59.2, T1.2 (E)
unnamed: R68.2, T40.2 (E)
unnamed: R67.2, T39.2 (E)
unnamed: R66.2, T38.2 (E)
unnamed: R65.2, T37.2 (E)
unnamed: R64.2, T36.2 (E)
unnamed: R63.2, T35.2 (E)
unnamed: R62.2, T34.2 (E)
unnamed: R61.2, T33.2 (E)
unnamed: R60.2, T12.2 (E)
unnamed: D5.4 (G-), R72.1
unnamed: D5.3 (R-), R71.1
unnamed: D5.2 (B-), R70.1
unnamed: D8.4 (G-), R79.1
unnamed: D8.3 (R-), R80.1
unnamed: D8.2 (B-), R81.1
unnamed: D6.4 (G-), R73.1
unnamed: D6.3 (R-), R74.1
unnamed: D6.2 (B-), R75.1
unnamed: D7.2 (B-), R78.1
unnamed: D7.3 (R-), R77.1
unnamed: D7.4 (G-), R76.1
U_!OE: U9.20 (!OE); also elsewhere on the board
U_SCL: U9.23 (SCL); also elsewhere on the board
U_SDA: U9.24 (SDA); also elsewhere on the board
V+: C30.1, C31.1, C32.1, D5.1 (+), D6.1 (+), D7.1 (+), D8.1 (+), U9.25 (VDD), U9.27 (A1); also elsewhere on the board

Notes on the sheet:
Nixie Drivers and Tubes (Hours)
gfcwfzkm - 2021 F

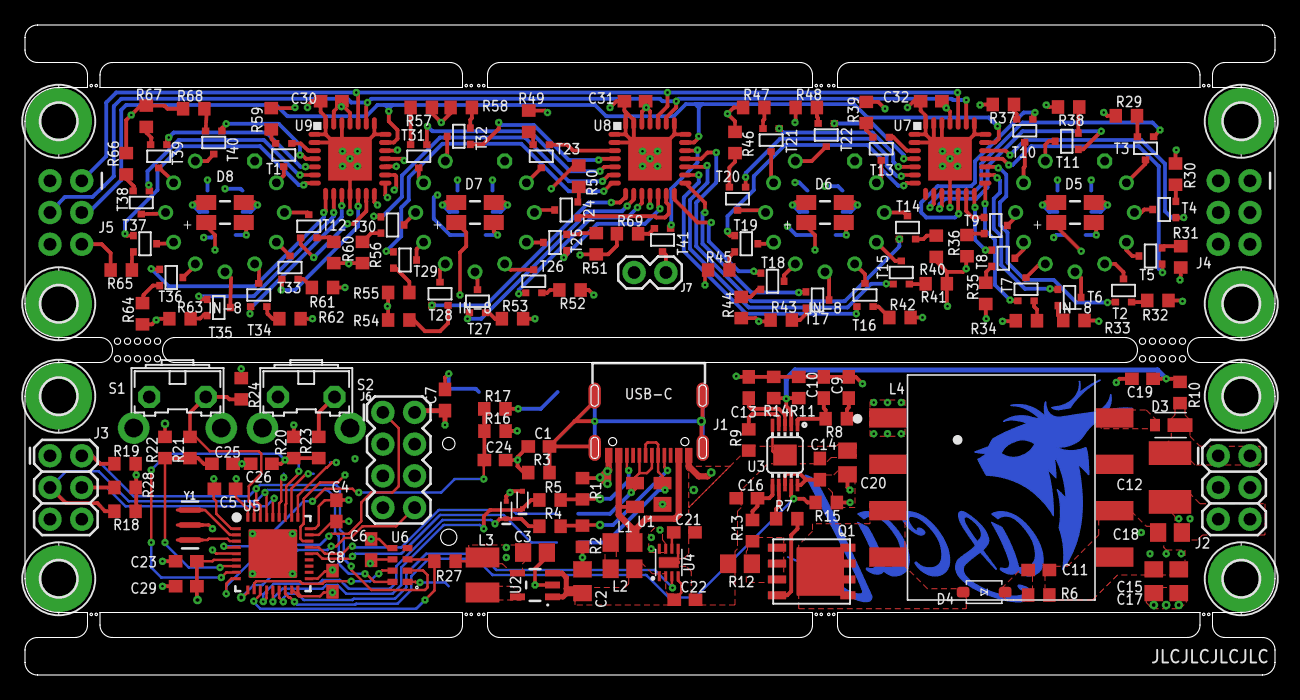
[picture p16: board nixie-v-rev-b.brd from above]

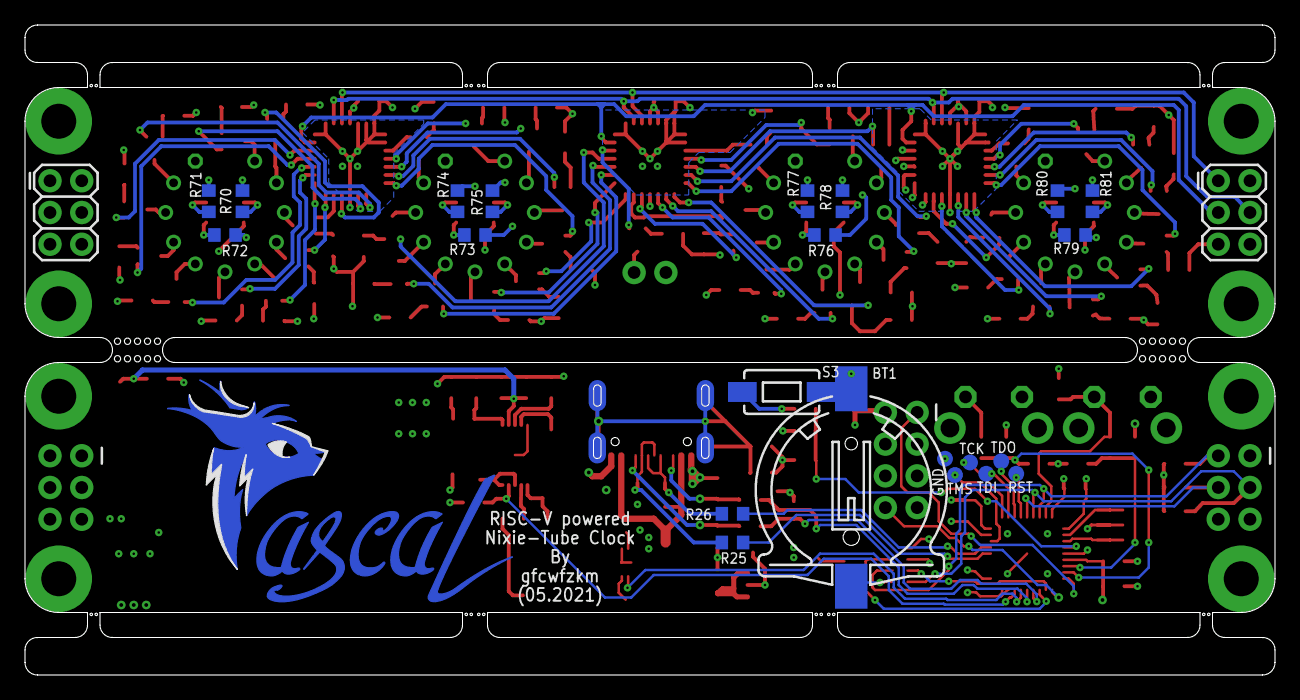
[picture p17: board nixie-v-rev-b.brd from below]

Board: 4 copper layers, 100.0 x 52.0 mm, 209 parts (25 on the bottom side), 200 nets.

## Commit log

2021-05-06 Initial upload of the schematics & layout
    [nixie-v-rev-b.brd, nixie-v-rev-b.sch]
2021-05-06 Initial upload
    Contains Gerber ZIP, PDF Exports of the eagle schematics & layout as well as the BOM as excel
    [nixie-v-rev-b.xlsx]
2021-06-15 Uploaded images of initial Revision A prototype
    Images of the first revision prototype, including a basic power-ON test with the LEDs turned on.
2021-06-15 Added Info of the circuit / project

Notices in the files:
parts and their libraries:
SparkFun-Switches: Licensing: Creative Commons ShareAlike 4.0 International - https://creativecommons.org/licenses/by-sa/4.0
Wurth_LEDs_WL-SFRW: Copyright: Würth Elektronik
